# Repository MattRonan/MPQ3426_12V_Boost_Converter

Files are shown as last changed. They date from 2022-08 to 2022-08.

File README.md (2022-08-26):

# MPQ3426_Boost_Converter

I made this 3.7V to 12V boost board to be able to power little solenoids from lipo packs.  All caps should be greater than 12V, diode should be at least 3A, and the inductor should have an Isat value of at least 5A.

MPQ3426_3V7to12V_2022-Aug-26_06-57-19PM-000_CustomizedView47584964517

Made with Eagle 9.6

Osh Park link: https://oshpark.com/shared_projects/3ssml9ry

brd

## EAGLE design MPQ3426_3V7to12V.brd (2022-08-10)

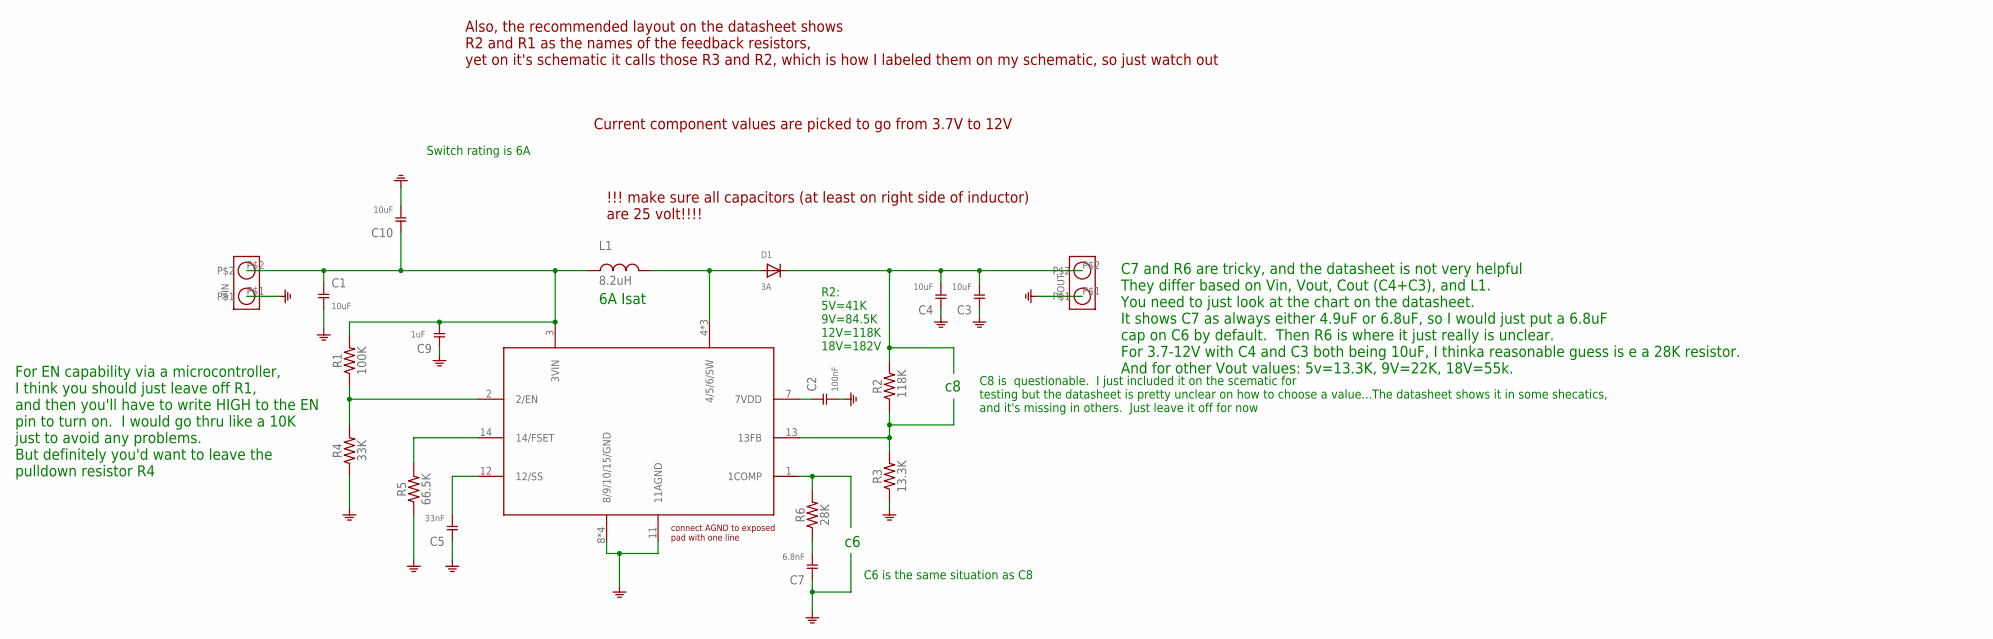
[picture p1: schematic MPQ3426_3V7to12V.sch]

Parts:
C1, C3, C4, C10: 10uF; 0805-NORMAL
C2: 100nF; 0603_NORMAL
C5: 33nF; 0603_NORMAL
C7: 6.8nF; 0603_NORMAL
C9: 1uF; 0603_NORMAL
D1: 3A; SOD-123FL
L1: 8.2uH; INDUCTOR_UNIVERSAL_LARGE
R1: 100K; 0603_NORMAL
R2: 118K; 0603_NORMAL
R3: 13.3K; 0603_NORMAL
R4: 33K; 0603_NORMAL
R5: 66.5K; 0603_NORMAL
R6: 28K; 0603_NORMAL
U$1: MPQ3426
VIN: HEADER_1X2_SQUARE_SMD; 1X2_.1"_2.54_SMD
VOUT: HEADER_1X2_SQUARE_SMD; 1X2_.1"_2.54_SMD

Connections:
GND: C1.2, C2.2, C3.1, C4.1, C5.1, C7.1, C9.1, C10.2, R3.1, R4.1, R5.1, U$1.8 (8/9/10/15/GND), U$1.9 (8/9/10/15/GND), U$1.10 (8/9/10/15/GND), U$1.11 (11AGND), U$1.P$1 (8/9/10/15/GND), VIN.P$1, VOUT.P$1
unnamed: D1.A, L1.P$2 (2), U$1.4 (4/5/6/SW), U$1.5 (4/5/6/SW), U$1.6 (4/5/6/SW)
unnamed: R1.1, R4.2, U$1.2 (2/EN)
unnamed: R5.2, U$1.14 (14/FSET)
unnamed: C5.2, U$1.12 (12/SS)
unnamed: C2.1, U$1.7 (7VDD)
unnamed: R2.1, R3.2, U$1.13 (13FB)
unnamed: R6.2, U$1.1 (1COMP)
unnamed: C7.2, R6.1
VIN: C1.1, C9.2, C10.1, L1.P$1 (1), R1.2, U$1.3 (3VIN), VIN.P$2
VOUT: C3.2, C4.2, D1.C, R2.2, VOUT.P$2

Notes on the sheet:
Switch rating is 6A
C8 is questionable. I just included it on the scematic for testing but the datasheet is pretty unclear on how to choose a value...The datasheet shows it in some shecatics, and it's missing in others. Just leave it off for now
C6 is the same situation as C8
R2: 5V=41K 9V=84.5K 12V=118K 18V=182V
!!! make sure all capacitors (at least on right side of inductor) are 25 volt!!!!
6A Isat
C7 and R6 are tricky, and the datasheet is not very helpful They differ based on Vin, Vout, Cout (C4+C3), and L1. You need to just look at the chart on the datasheet. It shows C7 as always either 4.9uF or 6.8uF, so I would just put a 6.8uF cap on C6 by default. Then R6 is where it just really is un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
Current component values are picked to go from 3.7V to 12V
Also, the recommended layout on the datasheet shows R2 and R1 as the names of the feedback resistors, yet on it's schematic it calls those R3 and R2, which is how I labeled them on my schematic, so just watch out
For EN capability via a microcontroller, I think you should just leave off R1, and then you'll have to write HIGH to the EN pin to turn on. I would go thru like a 10K just to avoid any problems. But definitely you'd want to leave the pulldown resistor R4

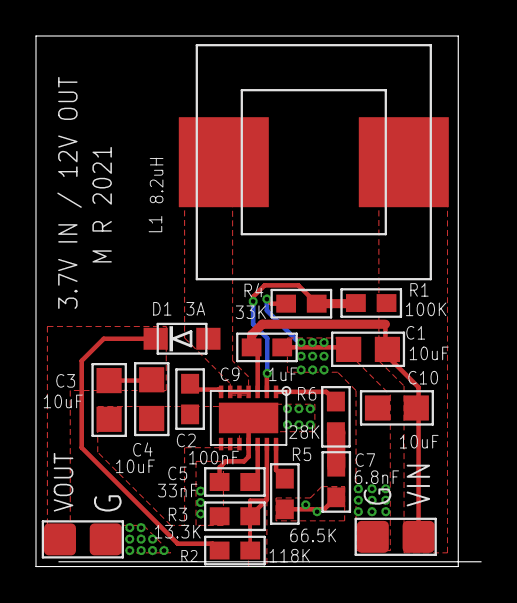
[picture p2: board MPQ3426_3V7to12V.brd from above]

Board: 2 copper layers, 24.7 x 29.5 mm, 19 parts (0 on the bottom side), 11 nets.
